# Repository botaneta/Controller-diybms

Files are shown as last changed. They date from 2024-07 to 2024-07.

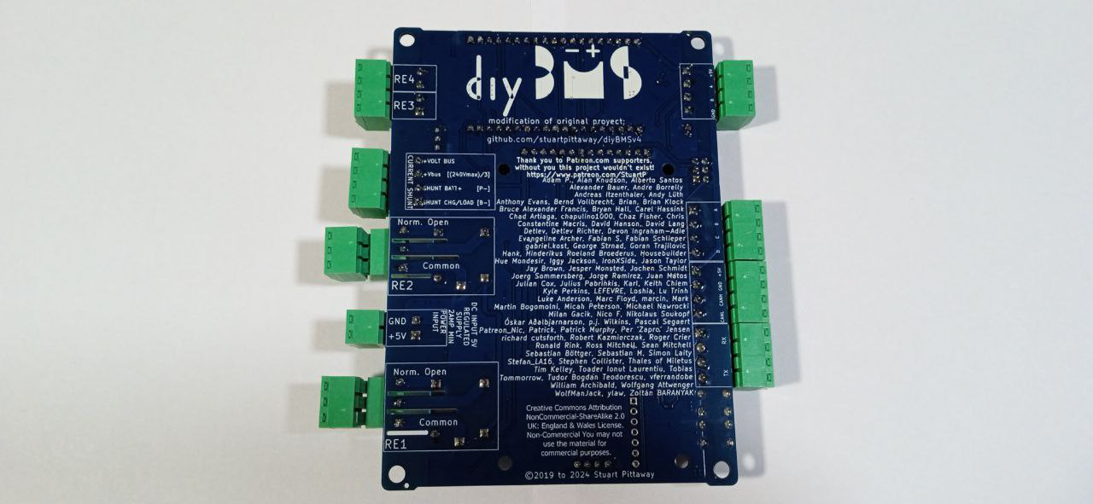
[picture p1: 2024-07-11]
imagenes/controller2.jpeg

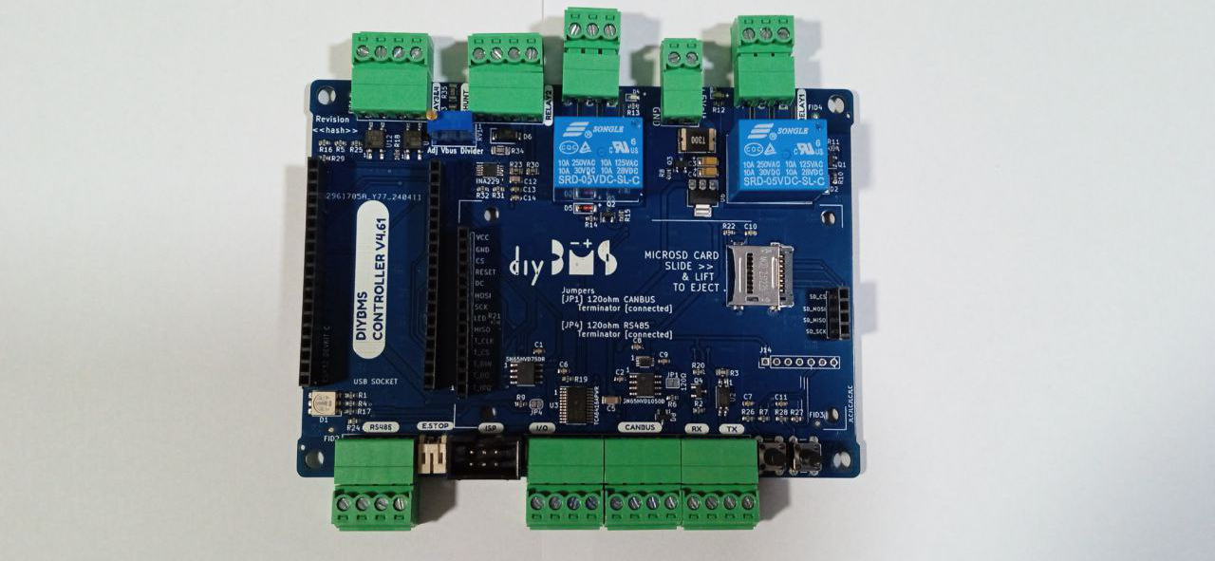
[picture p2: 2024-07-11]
imagenes/controller1.jpeg

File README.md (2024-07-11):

# Controller-diybms
Modificación del proyecto original diyBms de Stuart Pittaway https://github.com/stuartpittaway/diyBMSv4 <br>
Se añade un divisor de tensión a la placa controladora para medir mayor voltaje de batería con el monitor de corriente integrado.<br>
Esta modificación conyeva un riesgo electrico por manejar mayores voltajes, fuera de los limites de seguridad para las personas.<br>
No se recomienda su uso, aun teniendo los conocimientos adecuados. Lo seguro y recomendable es usar un monitor de corriente externo y aislado.

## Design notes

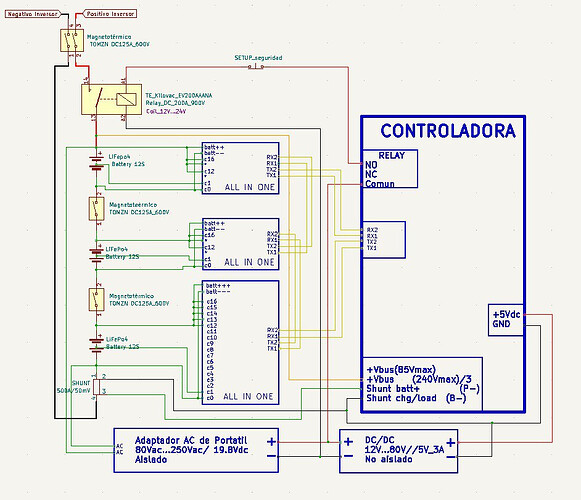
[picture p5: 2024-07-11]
imagenes/36sLifepoAll-in-one.jpeg

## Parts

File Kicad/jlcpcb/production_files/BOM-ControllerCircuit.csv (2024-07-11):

Comment | Designator | Footprint | LCSC
22K | R33,R34,R35 | R_1206_3216Metric | C102130
22uF 6.3V | C3,C4 | CP_EIA-3216-18_Kemet-A_Pad1.58x1.35mm_HandSolder | C110786
TCA6416APWR | U3 | TSSOP-24_4.4x7.8mm_P0.65mm | C130203
2x3 2.54mm IDC Connectors | J8 | PinHeader_2x03_P2.54mm_Vertical | C132438
SN65HVD1050D | U7 | SOIC-8_3.9x4.9mm_P1.27mm | C14019
100nF | C1,C14,C2,C6,C8,C9 | C_0603_1608Metric | C14663
AO3401A | Q3 | SOT-23 | C15127
ESTOP | J10 | JST_PH_S2B-PH-K_1x02_P2.00mm_Horizontal | C157932
1uF | C10,C11,C13,C7 | C_0603_1608Metric | C15849
Molex 0472192001 | J15 | 0472192001 | C164170
10R | R23,R30 | R_0805_2012Metric | C17415
LL4148 | D2,D5 | D_MiniMELF | C181117
RGB | D1 | LED_RGB_5050-6 | C219409
120R | R6,R8,R9 | R_0603_1608Metric | C22787
1M | R20 | R_0603_1608Metric | C22935
220R | R1,R17,R18,R21,R25 | R_0603_1608Metric | C22962
51K | R11,R15,R27,R7 | R_0603_1608Metric | C23196
560R | R10,R12,R13,R14,R4 | R_0603_1608Metric | C23204
180R | R3 | R_0805_2012Metric | C25270
10K | R19,R22,R29,R31,R32 | R_0603_1608Metric | C25804
LT219-1 | U12,U9 | SO-4_4.4x3.6mm_P2.54mm | C2691601
INA229 | U8 | VSSOP-10_3x3mm_P0.5mm | C2846803
4PinSocket | J16 | placeholder | C2905415
14PinSocket | J13 | placeholder | C2905420
19PinSocket | J11,J6 | placeholder | C2932678
NUP2105LT1G | D8 | SOT-23 | C2976509
22K | R24,R26,R28 | R_0603_1608Metric | C31850
EL3H7(B)(TA)-G | U2 | SOP-4_4.4x2.6mm_P1.27mm | C32565
AO3400A | Q1,Q2,Q4 | SOT-23 | C344010
SRD-05VDC-SL-C | K1,K2 | RELAY_SRD-05VDC-SL-C | C35449
ScrewTerminal3Pin | J2,J3 | Terminal-Block_5.0mm_3P-LCSC_C395850 | C395850
2K2 | R16,R2,R5 | R_0603_1608Metric | C4190
Fuse, 3A | F1 | Fuse_2920_7451Metric | C426964
SW_Push | SW1,SW2 | SW_PUSH_6mm_H5mm | C455101
TXS0102DCU | U1 | VSSOP-8_2.3x2mm_P0.5mm | C53434
22uF | C5 | C_1206_3216Metric | C5672
SN65HVD75DR | U5 | SOIC-8_3.9x4.9mm_P1.27mm | C57928
AMS1117-3.3 | U6 | SOT-223-3_TabPin2 | C6186
0.1uF-100V | C12 | C_0805_2012Metric | C696367
Z_82V | D6 | D_SMA | C700490
YELLOW LED | D3,D4 | LED_0603_1608Metric_Pad1.05x0.95mm_HandSolder | C72038
4PinBlock | J1,J12,J17,J4,J7,J9 | WJ15EDGRC-3.81-4P | C7245
5K | RV1 | Potentiometer_Bourns_3296W_Vertical | C780116
ScrewTerminal | J5 | WJ15EDGRC-3.81-2P | C8387
ESP32-DEVKITC-32D | U4 | MODULE_ESP32-DEVKITC-32D
OptTermination | JP1 | SolderJumper-2_P1.3mm_Bridged_Pad1.0x1.5mm
OptTermination | JP4 | SolderJumper-2_P1.3mm_Bridged_RoundedPad1.0x1.5mm
LCD | LCD1 | TFTSPI_2_8_240x320_TOUCH

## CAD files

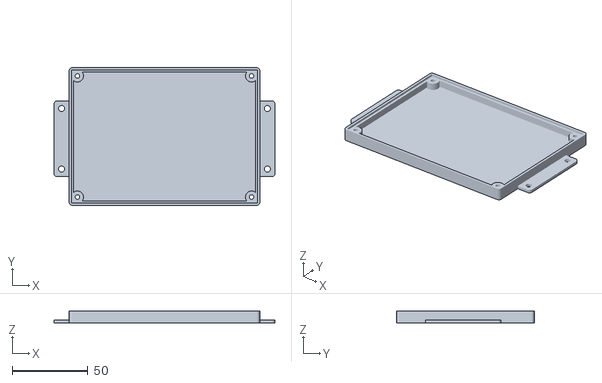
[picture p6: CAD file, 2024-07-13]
3D/marco_controladora.stl
146.0 x 91.0 x 8.00

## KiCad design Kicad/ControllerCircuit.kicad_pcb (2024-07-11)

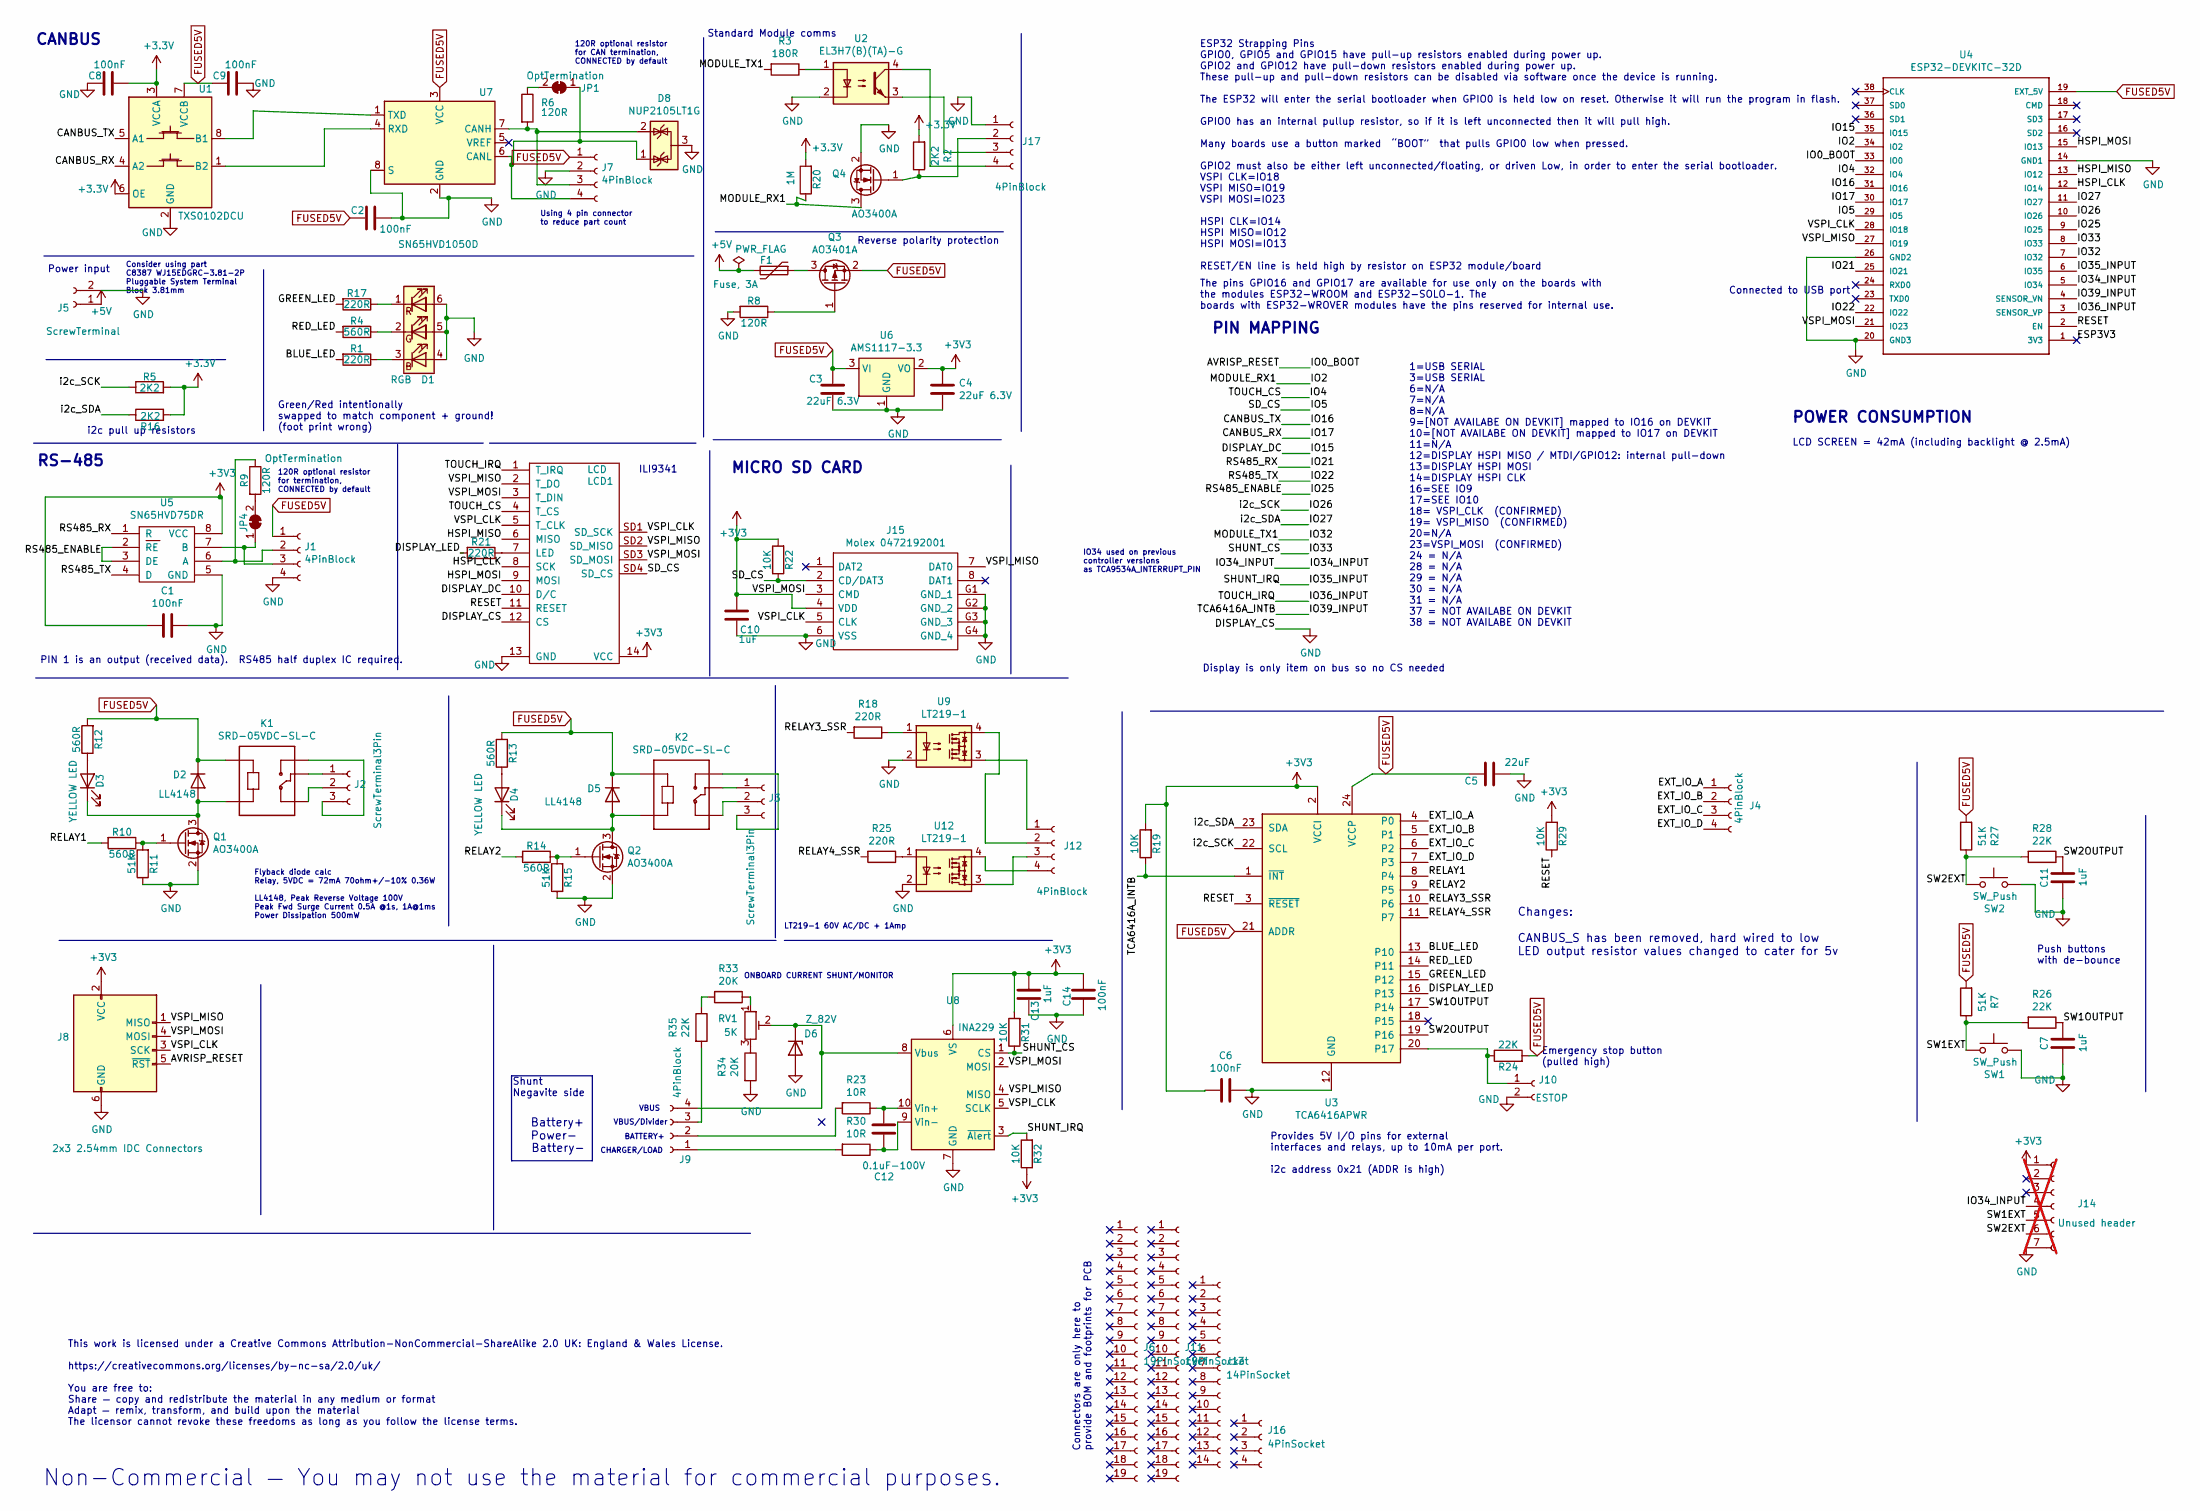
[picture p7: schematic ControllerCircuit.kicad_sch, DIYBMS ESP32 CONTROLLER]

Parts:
C1, C2, C6, C8, C9, C14: 100nF; C_0603_1608Metric; PartNumber CC0603KRX7R9BB104; LCSCStockCode C14663
C3, C4: 22uF 6.3V; CP_EIA-3216-18_Kemet-A_Pad1.58x1.35mm_HandSolder; PartNumber TC212A226K006Y; LCSCStockCode C110786
C5: 22uF; C_1206_3216Metric; PartNumber CL31A226KPHNNNE; LCSCStockCode C5672
C7, C10, C11, C13: 1uF; C_0603_1608Metric; PartNumber CL10A105KB8NNNC; LCSCStockCode C15849
C12: 0.1uF-100V; C_0805_2012Metric; PartNumber C0805C104K1RECAUTO; LCSCStockCode C696367
D1: RGB; LED_RGB_5050-6; LCSCStockCode C219409
D2, D5: LL4148; D_MiniMELF; PartNumber LL4148; LCSCStockCode C181117
D3, D4: YELLOW LED; LED_0603_1608Metric_Pad1.05x0.95mm_HandSolder; LCSCStockCode C72038
D6: Z_82V; D_SMA; LCSCStockCode C700490
D8: NUP2105LT1G; SOT-23; LCSCStockCode C2976509
F1: Fuse, 3A; Fuse_2920_7451Metric; PartNumber TLC-LSMD300D/16; LCSCStockCode C426964
J1, J4, J7, J9, J12, J17: 4PinBlock; WJ15EDGRC-3.81-4P; LCSCStockCode C7245
J2, J3: ScrewTerminal3Pin; Terminal-Block_5.0mm_3P-LCSC_C395850; LCSCStockCode C395850
J5: ScrewTerminal; WJ15EDGRC-3.81-2P; Manufacturer_Part_Number WJ15EDGRC-3.81-2P; LCSCStockCode C8387
J6, J11: 19PinSocket; Manufacturer_Part_Number KH-2.54FH-1X19P-H8.5; LCSCStockCode C2932678
J8: 2x3 2.54mm IDC Connectors; PinHeader_2x03_P2.54mm_Vertical; LCSCStockCode C132438
J10: ESTOP; JST_PH_S2B-PH-K_1x02_P2.00mm_Horizontal; PartNumber S2B-PH-K-S-GW; LCSCStockCode C157932
J13: 14PinSocket; Manufacturer_Part_Number KH-2.54FH-1X14P-H8.5; LCSCStockCode C2905420
J14: Unused header; PinHeader_1x07_P2.54mm_Vertical; not fitted
J15: Molex 0472192001; 0472192001; Manufacturer_Part_Number 0472192001; Mouser Part Number N/A
J16: 4PinSocket; Manufacturer_Part_Number KH-2.54FH-1X4P-H8.5; LCSCStockCode C2905415
JP1: OptTermination; SolderJumper-2_P1.3mm_Bridged_Pad1.0x1.5mm
JP4: OptTermination; SolderJumper-2_P1.3mm_Bridged_RoundedPad1.0x1.5mm
K1, K2: SRD-05VDC-SL-C; RELAY_SRD-05VDC-SL-C; PartNumber SRD-05VDC-SL-C; LCSCStockCode C35449
LCD1: LCD; TFTSPI_2_8_240x320_TOUCH
Q1, Q2, Q4: AO3400A; SOT-23; PartNumber AO3400A; LCSCStockCode C344010
Q3: AO3401A; SOT-23; LCSCStockCode C15127
R1, R17, R18, R21, R25: 220R; R_0603_1608Metric; PartNumber 0603WAF2200T5E; LCSCStockCode C22962
R2, R5, R16: 2K2; R_0603_1608Metric; PartNumber 0603WAF2201T5E; LCSCStockCode C4190
R3: 180R; R_0805_2012Metric; PartNumber 0805W8F1800T5E; LCSCStockCode C25270
R4, R10, R12, R13, R14: 560R; R_0603_1608Metric; PartNumber 0603WAF5600T5E; LCSCStockCode C23204
R6, R8, R9: 120R; R_0603_1608Metric; PartNumber 0603WAF1200T5E; LCSCStockCode C22787
R7, R11, R15, R27: 51K; R_0603_1608Metric; PartNumber 0603WAF5102T5E; LCSCStockCode C23196
R19, R22, R29, R31, R32: 10K; R_0603_1608Metric; PartNumber 0603WAF1002T5E; LCSCStockCode C25804
R20: 1M; R_0603_1608Metric; PartNumber 0603WAF1004T5E; LCSCStockCode C22935
R23, R30: 10R; R_0805_2012Metric; PartNumber 0805W8F100JT5E; LCSCStockCode C17415
R24, R26, R28: 22K; R_0603_1608Metric; PartNumber 0603WAF2202T5E; LCSCStockCode C31850
R33, R34: 20K; R_1206_3216Metric; LCSCStockCode C18003
R35: 22K; R_1206_3216Metric; LCSCStockCode C102130
RV1: 5K; Potentiometer_Bourns_3296W_Vertical; LCSCStockCode C780116
SW1, SW2: SW_Push; SW_PUSH_6mm_H5mm; PartNumber XUNPU TS-1002-10026; LCSCStockCode C455101
U1: TXS0102DCU; VSSOP-8_2.3x2mm_P0.5mm; LCSCStockCode C53434
U2: EL3H7(B)(TA)-G; SOP-4_4.4x2.6mm_P1.27mm; LCSCStockCode C32565
U3: TCA6416APWR; TSSOP-24_4.4x7.8mm_P0.65mm; LCSCStockCode C130203
U4: ESP32-DEVKITC-32D; MODULE_ESP32-DEVKITC-32D
U5: SN65HVD75DR; SOIC-8_3.9x4.9mm_P1.27mm; PartNumber SN65HVD75DR; LCSCStockCode C57928
U6: AMS1117-3.3; SOT-223-3_TabPin2; PartNumber AMS1117-3.3; LCSCStockCode C6186
U7: SN65HVD1050D; SOIC-8_3.9x4.9mm_P1.27mm; LCSCStockCode C14019
U8: INA229; VSSOP-10_3x3mm_P0.5mm; PartNumber INA229AIDGSR; LCSCStockCode C2846803
U9, U12: LT219-1; SO-4_4.4x3.6mm_P2.54mm; LCSCStockCode C2691601

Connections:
+5V: F1.2, J5.1
/AVRISP_RESET: J8.5 (~RST), U4.33 (IO0)
/BLUE_LED: R1.2, U3.13 (P10)
/CANBUS_RX: U1.4 (A2), U4.30 (IO17)
/CANBUS_TX: U1.5 (A1), U4.31 (IO16)
/DISPLAY_DC: LCD1.10 (D/C), U4.35 (IO15)
/DISPLAY_LED: R21.2, U3.16 (P13)
/ESP3V3: U4.1 (3V3)
/EXT_IO_A: J4.1, U3.4 (P0)
/EXT_IO_B: J4.2, U3.5 (P1)
/EXT_IO_C: J4.3, U3.6 (P2)
/EXT_IO_D: J4.4, U3.7 (P3)
/GREEN_LED: R17.2, U3.15 (P12)
/HSPI_CLK: LCD1.8 (SCK), U4.12 (IO14)
/HSPI_MISO: LCD1.6 (MISO), U4.13 (IO12)
/HSPI_MOSI: LCD1.9 (MOSI), U4.15 (IO13)
/IO2: Q4.3 (D), R20.1, U4.34 (IO2)
/IO4: LCD1.4 (T_CS), U4.32 (IO4)
/IO5: J15.2 (CD/DAT3), LCD1.SD4 (SD_CS), R22.1, U4.29 (IO5)
/IO21: U4.25 (IO21), U5.1 (R)
/IO22: U4.22 (IO22), U5.4 (D)
/IO25: U4.9 (IO25), U5.2 (RE), U5.3 (DE)
/IO26: R5.1, U3.22 (SCL), U4.10 (IO26)
/IO27: R16.1, U3.23 (SDA), U4.11 (IO27)
/IO32: R3.2, U4.7 (IO32)
/IO33: R31.1, U4.8 (IO33), U8.1 (CS)
/IO34_INPUT: J14.4, U4.5 (IO34)
/IO35_INPUT: R32.2, U4.6 (IO35), U8.3 (~Alert)
/IO36_INPUT: LCD1.1 (T_IRQ), U4.3 (SENSOR_VP)
/IO39_INPUT: R19.1, U3.1 (~INT), U4.4 (SENSOR_VN)
/RED_LED: R4.2, U3.14 (P11)
/RELAY1: R10.2, U3.8 (P4)
/RELAY2: R14.2, U3.9 (P5)
/RELAY3_SSR: R18.2, U3.10 (P6)
/RELAY4_SSR: R25.2, U3.11 (P7)
/RESET: LCD1.11 (RESET), R29.1, U3.3 (~RESET), U4.2 (EN)
/SW1EXT: J14.5, R7.1, R26.2, SW1.1
/SW1OUTPUT: C7.1, R26.1, U3.17 (P14)
/SW2EXT: J14.6, R27.1, R28.2, SW2.1
/SW2OUTPUT: C11.1, R28.1, U3.19 (P16)
/VSPI_CLK: J8.3 (SCK), J15.5 (CLK), LCD1.5 (T_CLK), LCD1.SD1 (SD_SCK), U4.28 (IO18), U8.5 (SCLK)
/VSPI_MISO: J8.1 (MISO), J15.7 (DAT0), LCD1.2 (T_DO), LCD1.SD2 (SD_MISO), U4.27 (IO19), U8.4 (MISO)
/VSPI_MOSI: J8.4 (MOSI), J15.3 (CMD), LCD1.3 (T_DIN), LCD1.SD3 (SD_MOSI), U4.21 (IO23), U8.2 (MOSI)
FUSED5V: C2.1, C3.1, C5.2, C9.1, D2.1 (K), D5.1 (K), J1.1, J7.1, K1.A1, K2.A1, Q3.2 (S), R7.2, R12.2, R13.2, R24.2, R27.2, U1.7 (VCCB), U3.21 (ADDR), U3.24 (VCCP), U4.19 (EXT_5V), U6.3 (VI), U7.3 (VCC)
GND: C1.2, C2.2, C3.2, C4.2, C5.1, C6.2, C7.2, C8.1, C9.2, C10.2, C11.2, C13.1, C14.1, D1.4 (BA), D1.5 (GA), D1.6 (RA), D6.2 (A), D8.3 (A), J1.4, J5.2, J7.2, J8.6 (GND), J10.2, J14.7, J15.6 (VSS), J15.G1 (GND_1), J15.G2 (GND_2), J15.G3 (GND_3), J15.G4 (GND_4), J17.1, LCD1.12 (CS), LCD1.13 (GND), Q1.2 (S), Q2.2 (S), Q4.2 (S), R8.2, R11.1, R15.1, R34.2, SW1.2, SW2.2, U1.2 (GND), U2.2, U3.12 (GND), U4.14 (GND1), U4.20 (GND3), U4.26 (GND2), U5.5 (GND), U6.1 (GND), U7.2 (GND), U7.8 (S), U8.7 (GND), U9.2, U12.2
unnamed: D1.3 (BK), R1.1
unnamed: D1.2 (GK), R4.1
unnamed: D1.1 (RK), R17.1
unnamed: D2.2 (A), D3.1 (K), K1.A2, Q1.3 (D)
unnamed: D3.2 (A), R12.1
unnamed: D4.2 (A), R13.1
unnamed: D4.1 (K), D5.2 (A), K2.A2, Q2.3 (D)
unnamed: D6.1 (K), J9.4, RV1.2, U8.8 (Vbus)
unnamed: J1.2, R9.1, U5.6 (A)
unnamed: J1.3, JP4.1 (A), U5.7 (B)
unnamed: J2.1, K1.COM
unnamed: J2.2, K1.NC
unnamed: J2.3, K1.NO
unnamed: J3.1, K2.COM
unnamed: J3.2, K2.NC
unnamed: J3.3, K2.NO
unnamed: D8.2 (K), J7.3, R6.2, U7.7 (CANH)
unnamed: D8.1 (K), J7.4, JP1.1 (A), U7.6 (CANL)
unnamed: J9.1, R30.2
unnamed: J9.2, R23.2
unnamed: J9.3, R35.2
unnamed: J10.1, R24.1, U3.20 (P17)
unnamed: J12.1, U9.3
unnamed: J12.2, U9.4
unnamed: J12.3, U12.3
unnamed: J12.4, U12.4
unnamed: J17.2, Q4.1 (G), R2.1
unnamed: J17.3, U2.3
unnamed: J17.4, U2.4
unnamed: JP1.2 (B), R6.1
unnamed: JP4.2 (B), R9.2
unnamed: LCD1.7 (LED), R21.1
unnamed: Q1.1 (G), R10.1, R11.2
unnamed: Q2.1 (G), R14.1, R15.2
unnamed: F1.1, Q3.3 (D)
unnamed: Q3.1 (G), R8.1
unnamed: R3.1, U2.1
unnamed: R18.1, U9.1
unnamed: R25.1, U12.1
unnamed: R33.1, RV1.1
unnamed: R33.2, R35.1
unnamed: R34.1, RV1.3
unnamed: U1.8 (B1), U7.1 (TXD)
unnamed: U1.1 (B2), U7.4 (RXD)
unnamed: C12.1, R23.1, U8.10 (Vin+)
unnamed: C12.2, R30.1, U8.9 (Vin-)

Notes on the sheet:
Standard Module comms
ILI9341
CANBUS
Push buttons with de-bounce
Display is only item on bus so no CS needed
PIN 1 is an output (received data). RS485 half duplex IC required.
Changes: CANBUS_S has been removed, hard wired to low LED output resistor values changed to cater for 5v
Connectors are only here to provide BOM and footprints for PCB
Non-Commercial — You may not use the material for commercial purposes.
Shunt Negavite side
120R optional resistor for CAN termination, CONNECTED by default
Consider using part C8387 WJ15EDGRC-3.81-2P Pluggable System Terminal Block 3.81mm
Connected to USB port
Reverse polarity protection
PIN MAPPING
ESP32 Strapping Pins GPIO0, GPIO5 and GPIO15 have pull-up resistors enabled during power up. GPIO2 and GPIO12 have pull-down resistors enabled during power up. These pull-up and pull-down resistors can be disabled via software once the device is running. The ESP32 will enter the serial bootloader w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
VBUS/Divider
Flyback diode calc Relay, 5VDC = 72mA 70ohm+/-10% 0.36W LL4148, Peak Reverse Voltage 100V Peak Fwd Surge Current 0.5A @1s, 1A@1ms Power Dissipation 500mW
POWER CONSUMPTION
Provides 5V I/O pins for external interfaces and relays, up to 10mA per port. i2c address 0x21 (ADDR is high)
i2c pull up resistors
LCD SCREEN = 42mA (including backlight @ 2.5mA)
CHARGER/LOAD
1=USB SERIAL 3=USB SERIAL 6=N/A 7=N/A 8=N/A 9=[NOT AVAILABE ON DEVKIT] mapped to IO16 on DEVKIT 10=[NOT AVAILABE ON DEVKIT] mapped to IO17 on DEVKIT 11=N/A 12=DISPLAY HSPI MISO / MTDI/GPIO12: internal pull-down 13=DISPLAY HSPI MOSI 14=DISPLAY HSPI CLK 16=SEE IO9 17=SEE IO10 18= VSPI_CLK (CONFIRMED)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
Emergency stop button (pulled high)
This work is licensed under a Creative Commons Attribution-NonCommercial-ShareAlike 2.0 UK: England & Wales License. https://creativecommons.org/licenses/by-nc-sa/2.0/uk/ You are free to: Share — copy and redistribute the material in any medium or format Adapt — remix, transform, and build upon the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
BATTERY+
The pins GPIO16 and GPIO17 are available for use only on the boards with the modules ESP32-WROOM and ESP32-SOLO-1. The boards with ESP32-WROVER modules have the pins reserved for internal use.
Power input
Battery-
Using 4 pin connector to reduce part count
Power-
Green/Red intentionally swapped to match component + ground! (foot print wrong)
ONBOARD CURRENT SHUNT/MONITOR
RS-485
IO34 used on previous controller versions as TCA9534A_INTERRUPT_PIN
Battery+
VBUS
LT219-1 60V AC/DC + 1Amp
120R optional resistor for termination, CONNECTED by default

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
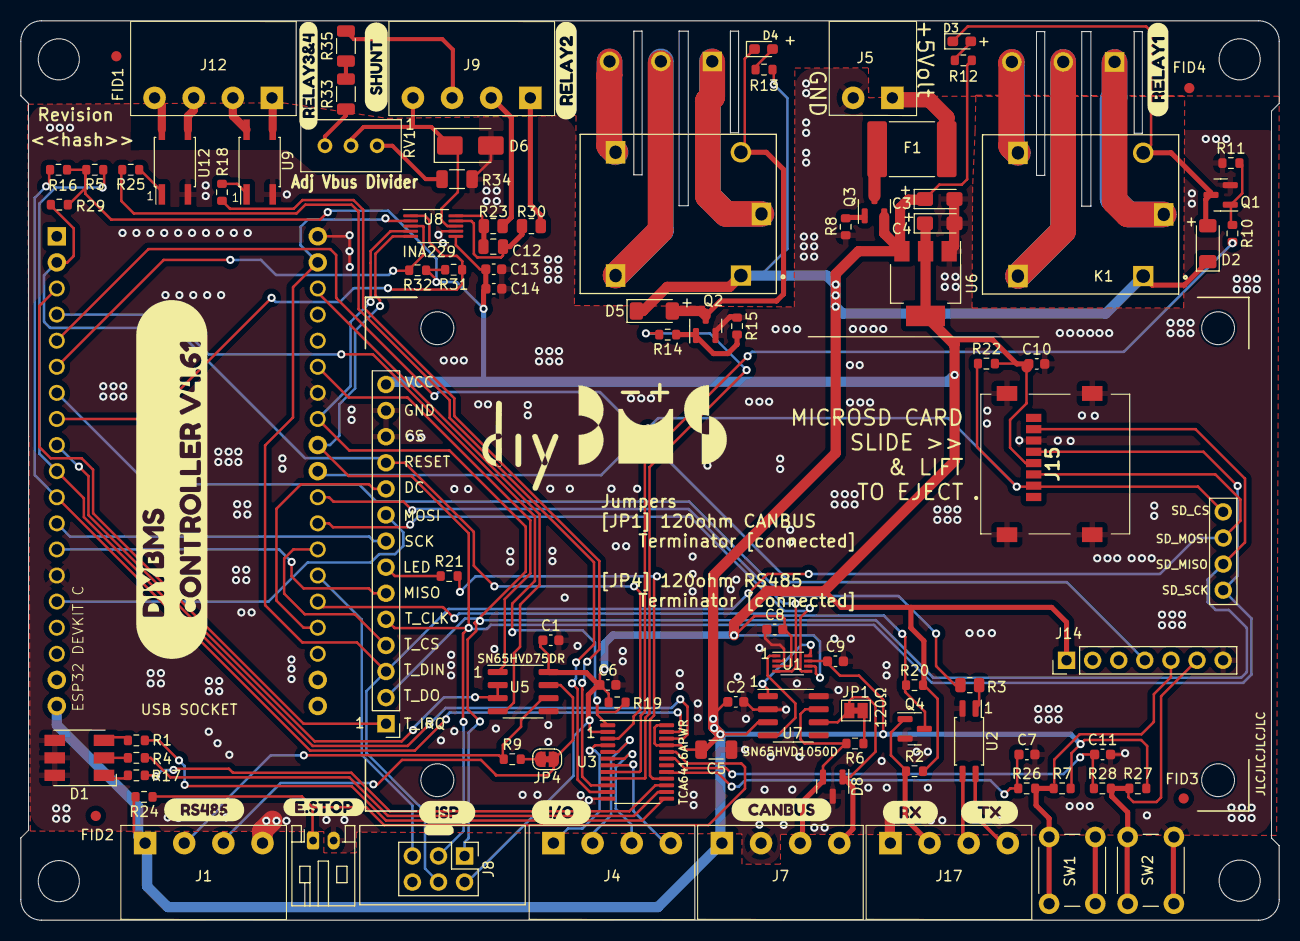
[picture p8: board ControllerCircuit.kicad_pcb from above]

Board: 2 copper layers, 122.5 x 87.5 mm, 118 parts (1 on the bottom side), 91 nets.

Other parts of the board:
FID1, FID2, FID3, FID4: Fiducial_1mm_Mask2mm
G99: LOGO; diybms_logo_24x10mm
REF1, REF2, REF3, REF4: MountingHole_4mm
e: LOGO; logo
kibuzzard-65B91D2D: G***; kibuzzard-65B91D2D
kibuzzard-65B91D57: G***; kibuzzard-65B91D57
kibuzzard-65B91DB3: G***; kibuzzard-65B91DB3
kibuzzard-65B91E2F: G***; kibuzzard-65B91E2F
kibuzzard-65B918A7: G***; kibuzzard-65B918A7
svg2mod1, svg2mod3, svg2mod4, svg2mod5, svg2mod6, svg2mod8, svg2mod55: G***; label

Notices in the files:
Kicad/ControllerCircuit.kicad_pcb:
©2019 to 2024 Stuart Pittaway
